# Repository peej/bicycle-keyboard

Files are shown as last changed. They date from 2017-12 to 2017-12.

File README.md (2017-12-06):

Bicycle is a 58 key ortholinear split keyboard PCB with a 5 key thumb cluster.

A more ergonomic version of the Let's Split keyboard, it adds an additional row to the matrix for use by a 30 degree angled thumb cluster of keys. Designed to be easy to build, it only supports serial communication over a TRRS cable and no LED support. The PCB is reversible, meaning that you need two of the same PCB to create a full keyboard.

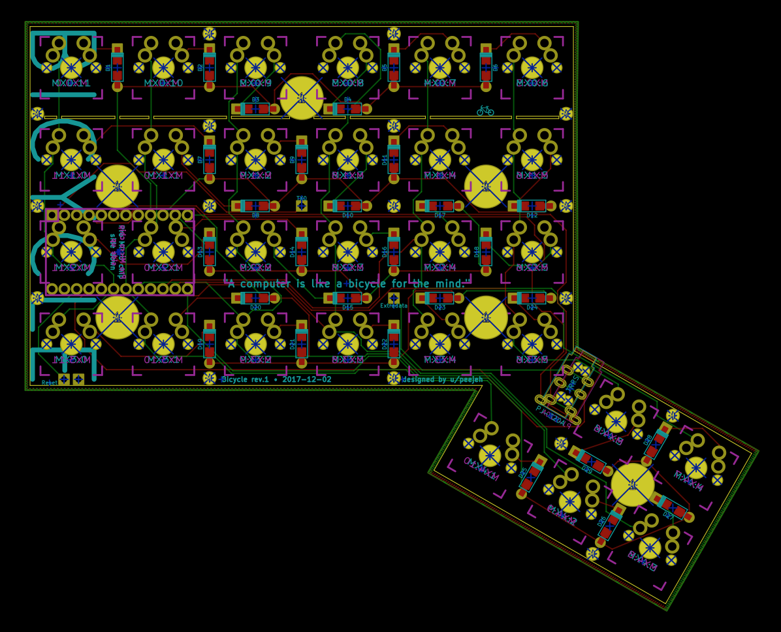
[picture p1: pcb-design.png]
PCB render from KiCad

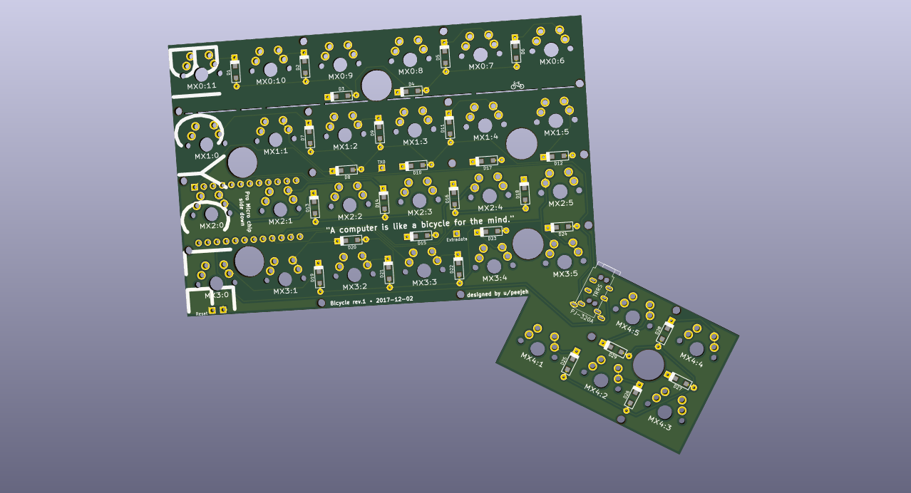
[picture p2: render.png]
3D render from KiCad

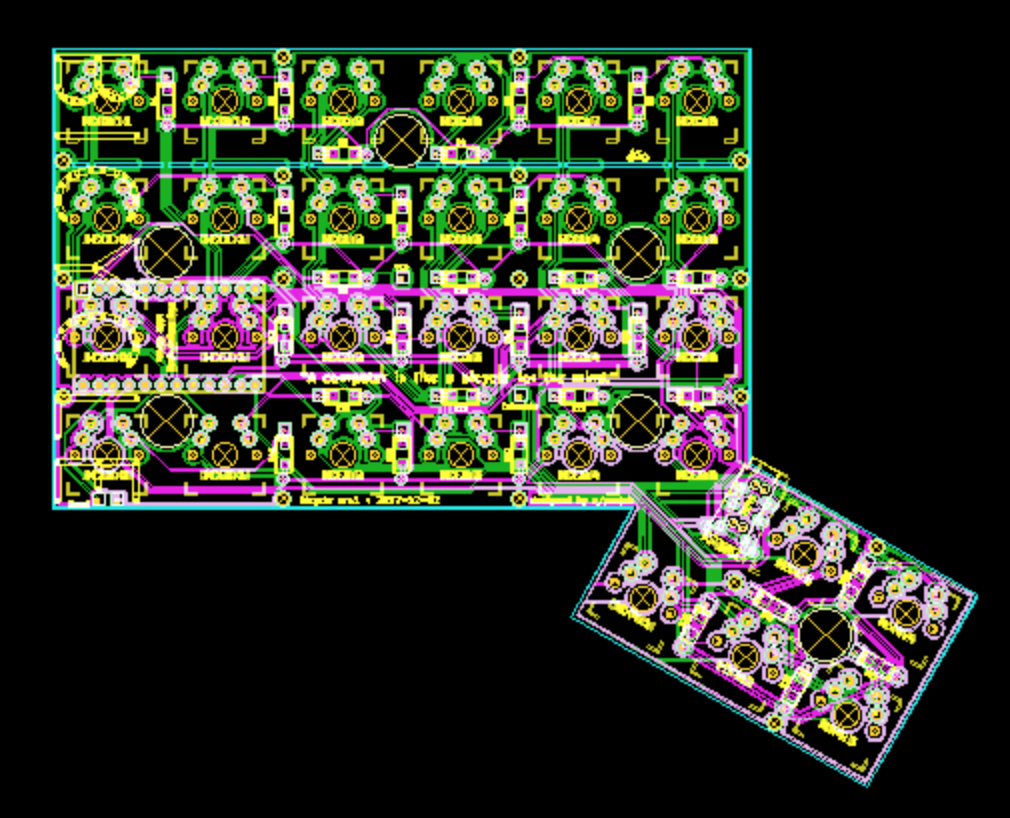
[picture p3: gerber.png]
Gerber file render


Documentation is a work in progress.

# BOM

* 2 PCBs, Gerber files for printing can be found in the repo.
* 58 MX compatible switches.
* 58 1n4148 diodes.
* 2 Pro Micros.
* 2 PJ320A 3.5mm TRRS jacks.
* TRRS cable and micro USB cable.

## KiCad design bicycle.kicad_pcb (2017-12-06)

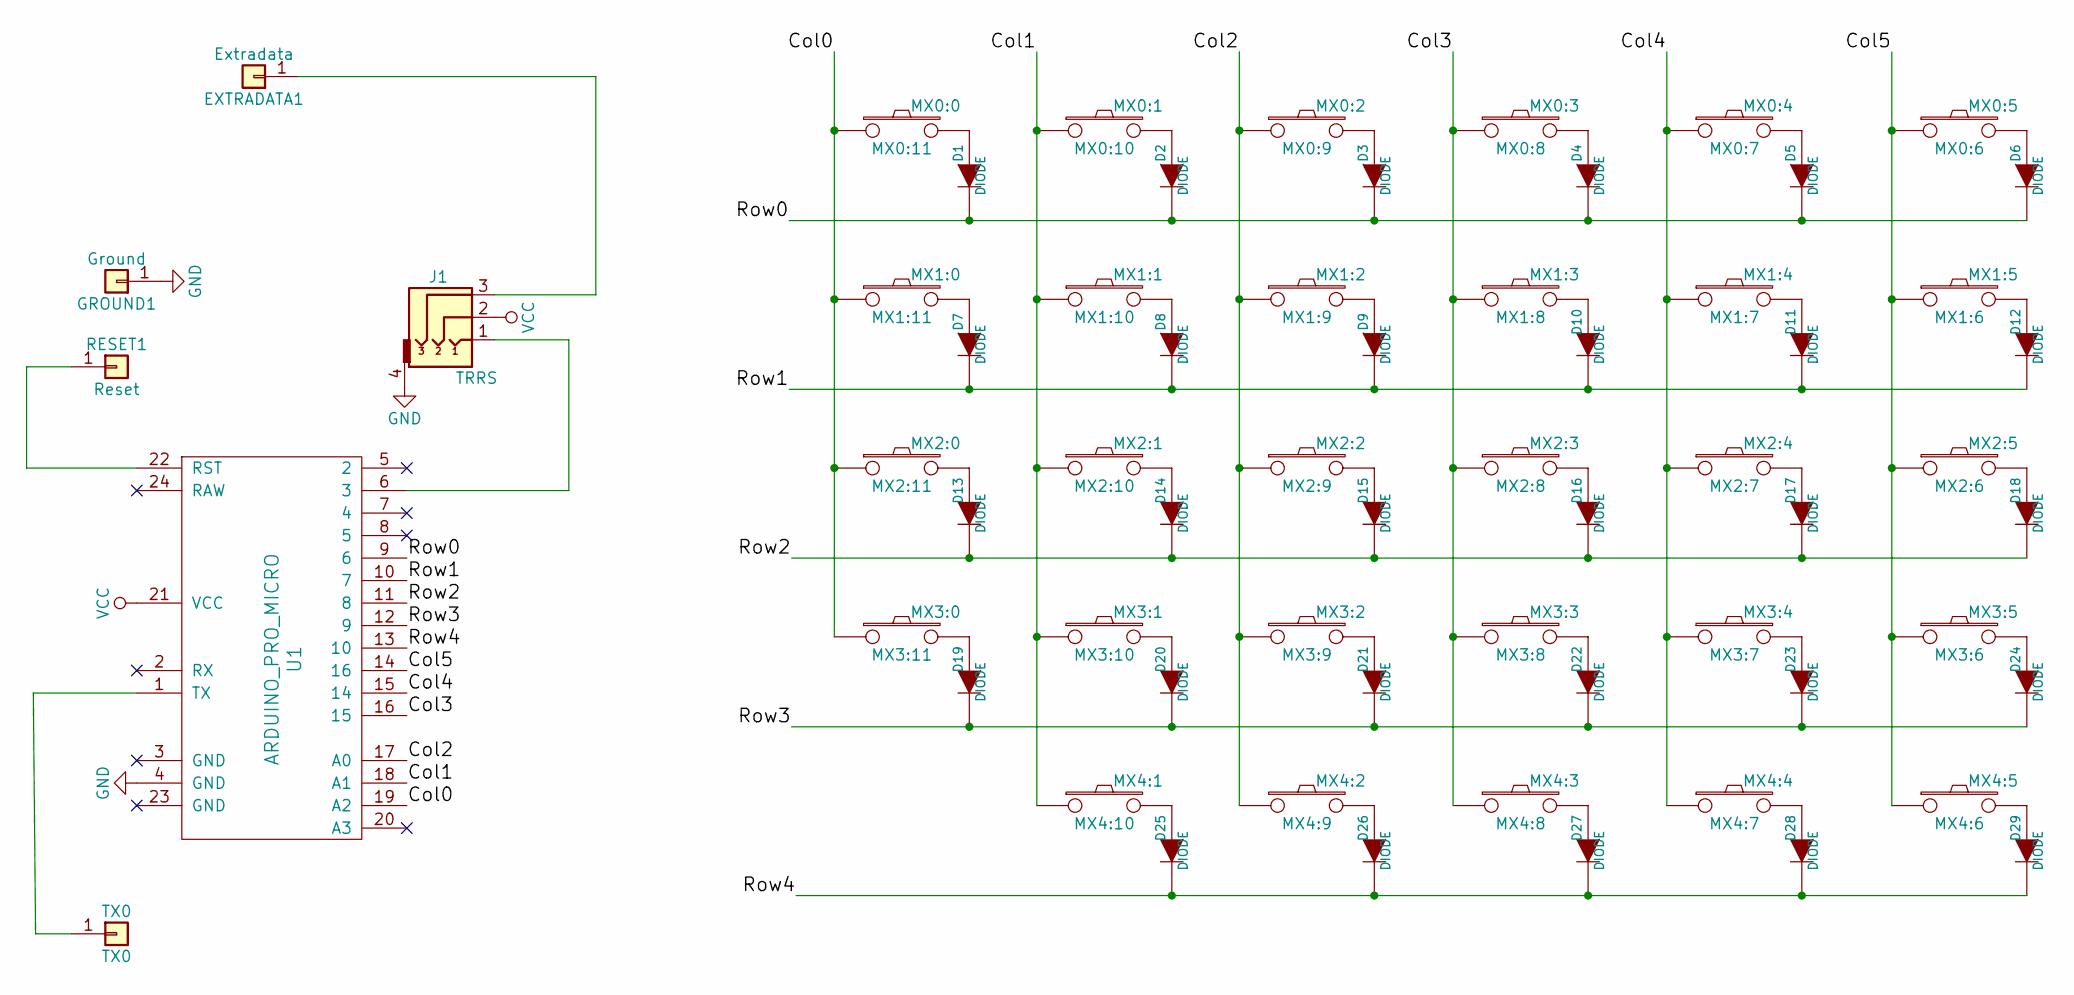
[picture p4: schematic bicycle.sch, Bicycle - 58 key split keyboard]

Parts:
D1, D2, D3, D4, D5, D6, D7, D8, D9, D10, D11, D12, D13, D14, D15, D16, D17, D18, D19, D20, D21, D22, D23, D24, D25, D26, D27, D28, D29: DIODE; D_SOD123_axial
EXTRADATA1: Extradata; PIN_1_SQUARE
GROUND1: Ground; PIN_1_SQUARE
J1: TRRS; PJ320A_3.5mm_Jack
MX0:0: MX0:11; MX_DoubleSided
MX0:1: MX0:10; MX_DoubleSided
MX0:2: MX0:9; MX_DoubleSided
MX0:3: MX0:8; MX_DoubleSided
MX0:4: MX0:7; MX_DoubleSided
MX0:5: MX0:6; MX_DoubleSided
MX1:0: MX1:11; MX_DoubleSided
MX1:1: MX1:10; MX_DoubleSided
MX1:2: MX1:9; MX_DoubleSided
MX1:3: MX1:8; MX_DoubleSided
MX1:4: MX1:7; MX_DoubleSided
MX1:5: MX1:6; MX_DoubleSided
MX2:0: MX2:11; MX_DoubleSided
MX2:1: MX2:10; MX_DoubleSided
MX2:2: MX2:9; MX_DoubleSided
MX2:3: MX2:8; MX_DoubleSided
MX2:4: MX2:7; MX_DoubleSided
MX2:5: MX2:6; MX_DoubleSided
MX3:0: MX3:11; MX_DoubleSided
MX3:1: MX3:10; MX_DoubleSided
MX3:2: MX3:9; MX_DoubleSided
MX3:3: MX3:8; MX_DoubleSided
MX3:4: MX3:7; MX_DoubleSided
MX3:5: MX3:6; MX_DoubleSided
MX4:1: MX4:10; MX_DoubleSided
MX4:2: MX4:9; MX_DoubleSided
MX4:3: MX4:8; MX_DoubleSided
MX4:4: MX4:7; MX_DoubleSided
MX4:5: MX4:6; MX_DoubleSided
RESET1: Reset; PIN_1_SQUARE
TX0: TX0; PIN_1_SQUARE
U1: ARDUINO_PRO_MICRO

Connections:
/Col0: MX0:0.1, MX1:0.1, MX2:0.1, MX3:0.1, U1.19 (A2)
/Col1: MX0:1.1, MX1:1.1, MX2:1.1, MX3:1.1, MX4:1.1, U1.18 (A1)
/Col2: MX0:2.1, MX1:2.1, MX2:2.1, MX3:2.1, MX4:2.1, U1.17 (A0)
/Col3: MX0:3.1, MX1:3.1, MX2:3.1, MX3:3.1, MX4:3.1, U1.16 (15)
/Col4: MX0:4.1, MX1:4.1, MX2:4.1, MX3:4.1, MX4:4.1, U1.15 (14)
/Col5: MX0:5.1, MX1:5.1, MX2:5.1, MX3:5.1, MX4:5.1, U1.14 (16)
/Row0: D1.2 (K), D2.2 (K), D3.2 (K), D4.2 (K), D5.2 (K), D6.2 (K), U1.9 (6)
/Row1: D7.2 (K), D8.2 (K), D9.2 (K), D10.2 (K), D11.2 (K), D12.2 (K), U1.10 (7)
/Row2: D13.2 (K), D14.2 (K), D15.2 (K), D16.2 (K), D17.2 (K), D18.2 (K), U1.11 (8)
/Row3: D19.2 (K), D20.2 (K), D21.2 (K), D22.2 (K), D23.2 (K), D24.2 (K), U1.12 (9)
/Row4: D25.2 (K), D26.2 (K), D27.2 (K), D28.2 (K), D29.2 (K), U1.13 (10)
GND: GROUND1.1, J1.4, U1.4 (GND)
unnamed: D1.1 (A), MX0:0.2
unnamed: D2.1 (A), MX0:1.2
unnamed: D3.1 (A), MX0:2.2
unnamed: D4.1 (A), MX0:3.2
unnamed: D5.1 (A), MX0:4.2
unnamed: D6.1 (A), MX0:5.2
unnamed: D7.1 (A), MX1:0.2
unnamed: D8.1 (A), MX1:1.2
unnamed: D9.1 (A), MX1:2.2
unnamed: D10.1 (A), MX1:3.2
unnamed: D11.1 (A), MX1:4.2
unnamed: D12.1 (A), MX1:5.2
unnamed: D13.1 (A), MX2:0.2
unnamed: D14.1 (A), MX2:1.2
unnamed: D15.1 (A), MX2:2.2
unnamed: D16.1 (A), MX2:3.2
unnamed: D17.1 (A), MX2:4.2
unnamed: D18.1 (A), MX2:5.2
unnamed: D19.1 (A), MX3:0.2
unnamed: D20.1 (A), MX3:1.2
unnamed: D21.1 (A), MX3:2.2
unnamed: D22.1 (A), MX3:3.2
unnamed: D23.1 (A), MX3:4.2
unnamed: D24.1 (A), MX3:5.2
unnamed: D25.1 (A), MX4:1.2
unnamed: D26.1 (A), MX4:2.2
unnamed: D27.1 (A), MX4:3.2
unnamed: D28.1 (A), MX4:4.2
unnamed: D29.1 (A), MX4:5.2
unnamed: EXTRADATA1.1, J1.3
unnamed: J1.1, U1.6 (3)
unnamed: RESET1.1, U1.22 (RST)
unnamed: TX0.1, U1.1 (TX)
VCC: J1.2, U1.21 (VCC)

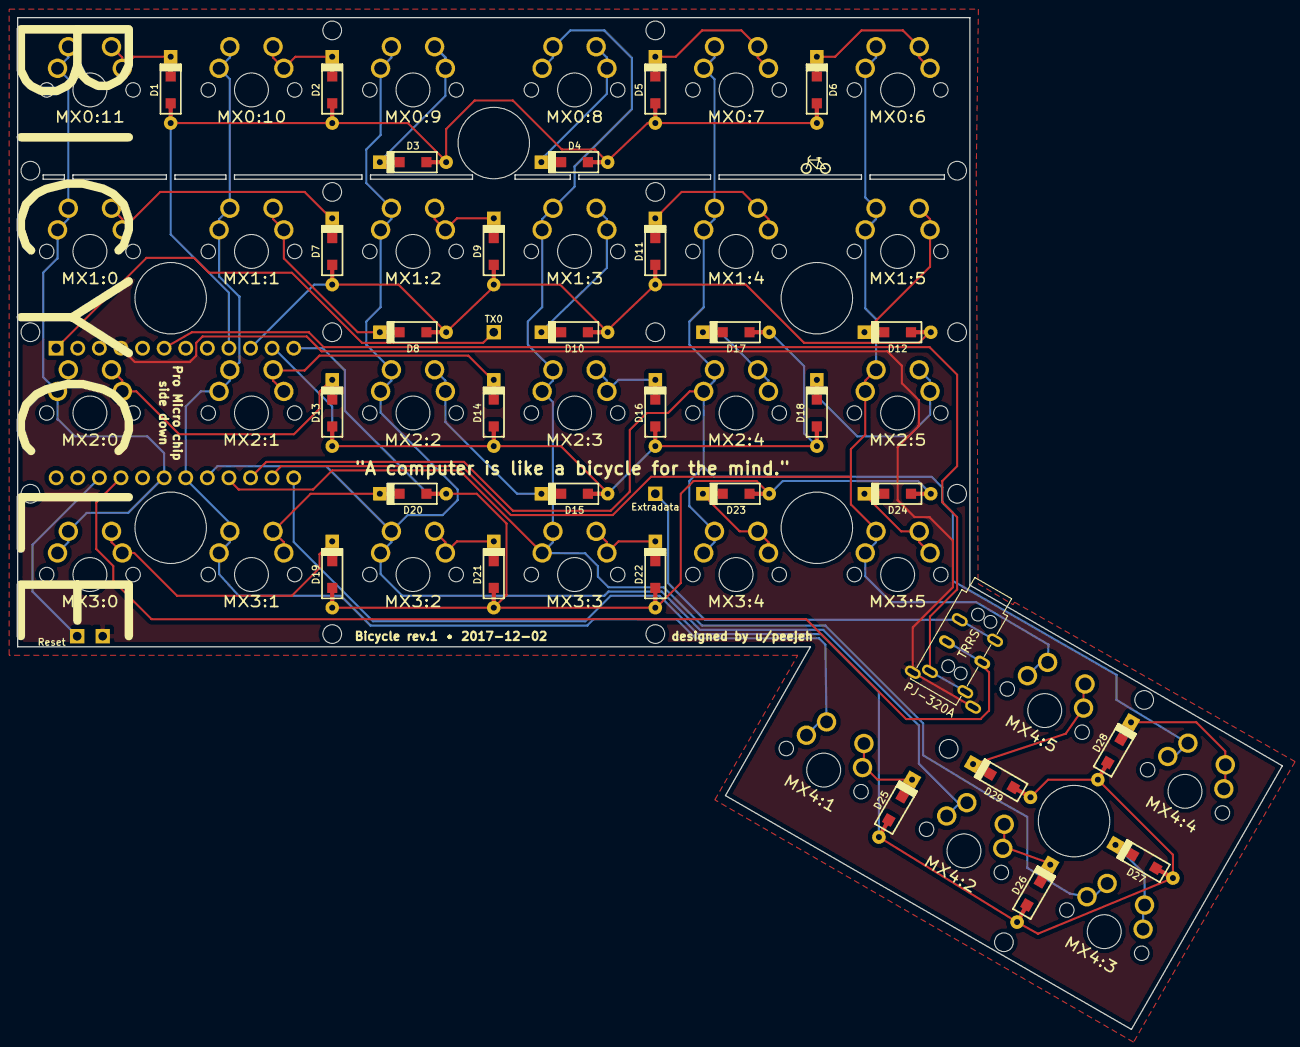
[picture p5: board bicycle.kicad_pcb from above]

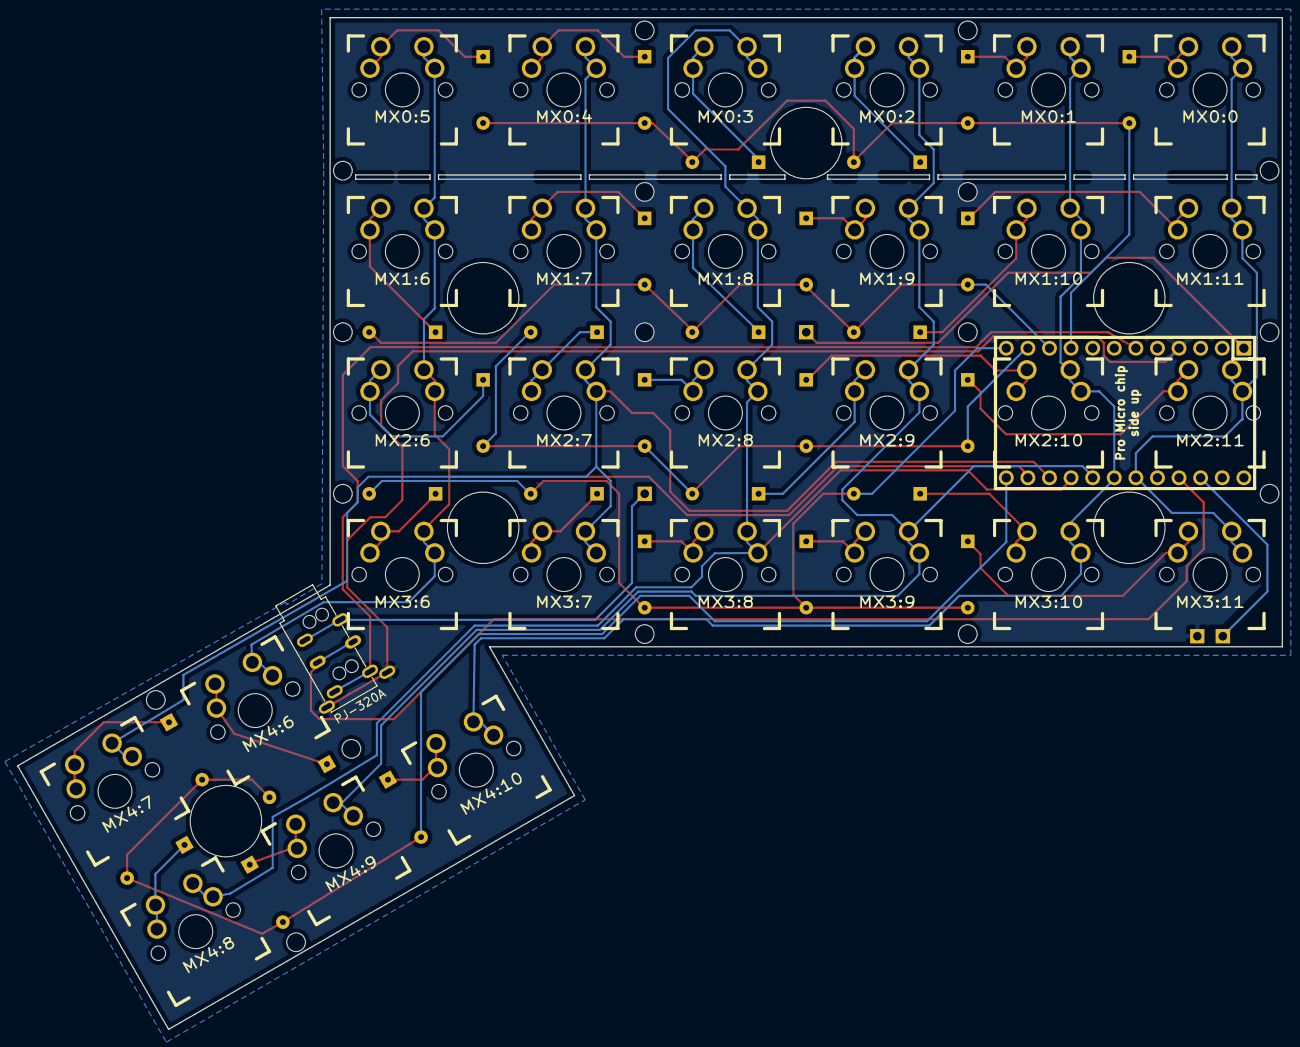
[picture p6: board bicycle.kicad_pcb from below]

Board: 2 copper layers, 148.8 x 119.0 mm, 87 parts (30 on the bottom side), 46 nets.

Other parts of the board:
M2, M2#2, M2#3, M2#4, M2#5, M2#6, M2#7, M2#8, M2#9, M2#10, M2#11, M2#12, M2#13, M2#14, M2#15, M2#16, M2#17: MountingHole_2.2mm_M2
M8, M8#2, M8#3, M8#4, M8#5, M8#6: MountingHole_8.4mm_M8

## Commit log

2017-12-06 Add PCB files
    [bicycle.kicad_pcb, bicycle.sch]
2017-12-06 Add plate PCB
    [plate.kicad_pcb]
2017-12-06 Add gerber files
    [bicycle-B.Cu.gbl, bicycle-B.Mask.gbs, bicycle-B.SilkS.gbo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]
